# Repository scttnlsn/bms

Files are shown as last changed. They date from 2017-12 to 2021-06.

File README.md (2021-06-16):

# BMS

Integrated battery management system for 4-series li-ion packs (based on the [BQ76920](http://www.ti.com/product/BQ76920) from Texas Instruments).

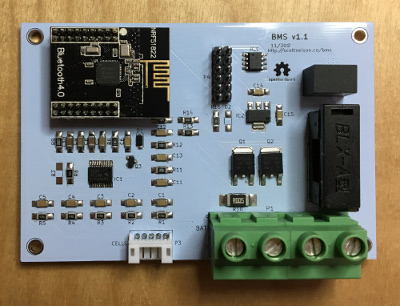
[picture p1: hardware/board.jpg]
Board


* programmable over/under voltage protection for each cell
* programmable short-circuit detection
* auto cell balancing
* cell voltage monitoring
* coulomb counting for accurate state-of-charge tracking
* status available over BLE

## Hardware

Full schematic and PCB layout available in the `hardware` directory.

* [TI BQ76920](http://www.ti.com/product/BQ76920) analog front-end
* [Nordic nRF51822](https://www.nordicsemi.com/eng/Products/Bluetooth-low-energy/nRF51822) ARM Cortex-M host controller
* FETs for enabling or disabling charge/discharge
* shunt resistor for current measurement

## Firmware

The host controller firmware is based on the [Zephyr RTOS](https://www.zephyrproject.org).  It communicates with the BQ76920 via I2C and handles various error states that may occur in the BQ76920.  It also exposes a BLE peripheral for wireless monitoring.

### Build

Requirements:

* [GNU ARM Embedded Toolchain](https://developer.arm.com/open-source/gnu-toolchain/gnu-rm)
* [OpenOCD](http://openocd.org)
* [Zephyr RTOS](https://www.zephyrproject.org) (included as submodule)
* [elftools](https://github.com/eliben/pyelftools)

Setup:

* `git submodule update --init`
* `./setup.sh`

Compile and flash:

* `make`
* `make flash`

### Configuration

There are various configuration options which can be specified via Kconfig.  Run `make menuconfig` to browse the available options and override any of the default values.

* `CONFIG_BMS_BOOT_DEVICE` (default: `GPIO_0`)
* `CONFIG_BMS_BOOT_PIN` (default: `21`)
* `CONFIG_BMS_ALERT_DEVICE` (default: `GPIO_0`)
* `CONFIG_BMS_ALERT_PIN` (default: `22`)
* `CONFIG_BMS_BLINK_DEVICE` (default: `GPIO_0`)
* `CONFIG_BMS_BLINK_PIN` (default: `18`)
* `CONFIG_BMS_OVP_ENABLE` (default: `3550` mV)
* `CONFIG_BMS_OVP_DISABLE` (default: `3350` mV)
* `CONFIG_BMS_UVP_ENABLE` (default: `3000` mV)
* `CONFIG_BMS_UVP_DISABLE` (default: `3100` mV)
* `CONFIG_BMS_SCD_DELAY` (default: `10000` ms)
* `CONFIG_BMS_OCD_DELAY` (default: `10000` ms)

## BLE Protocol

The BMS implements a Bluetooth Low Energy peripheral for monitoring cell voltages, current draw and state-of-charge.  All status data is part of a single characteristic.

Peripheral UUID: `8D9D7800-5B61-412A-AB71-5C7E0E559086`

Characteristic UUID: `8D9D7801-5B61-412A-AB71-5C7E0E559086`

Value structure (MSB to LSB):

* status [1 byte]
* cell 1 (mV) [2 bytes]
* cell 2 (mV) [2 bytes]
* cell 3 (mV) [2 bytes]
* cell 4 (mV) [2 bytes]
* current (mA) [2 bytes signed]
* charge used (mAs) [4 bytes signed]
* state of charge (percent) [1 byte]

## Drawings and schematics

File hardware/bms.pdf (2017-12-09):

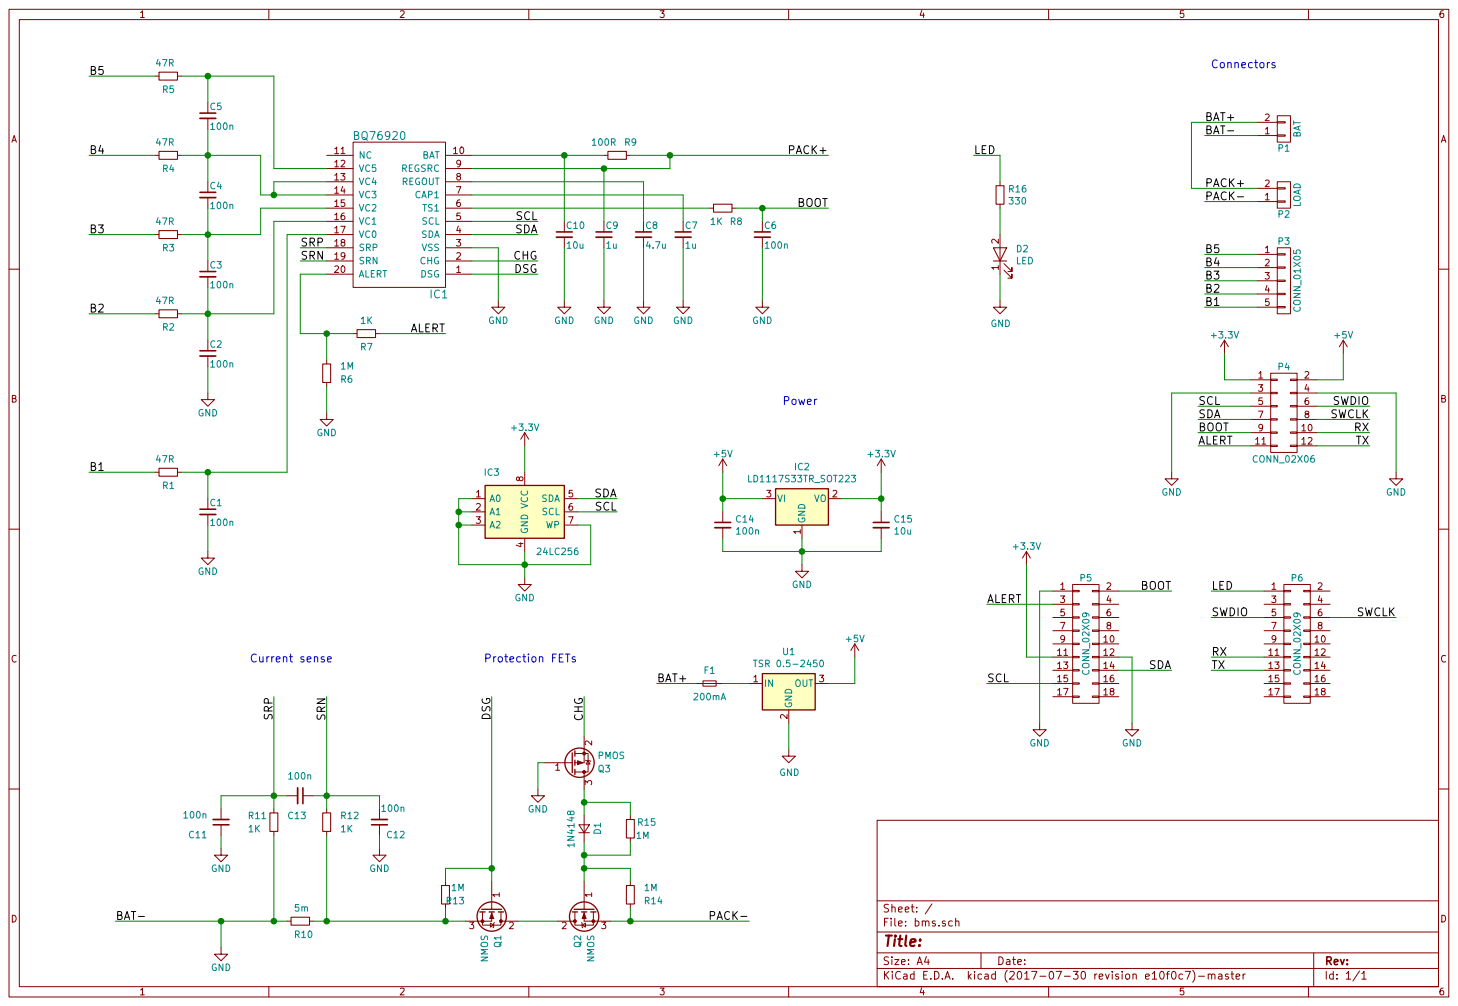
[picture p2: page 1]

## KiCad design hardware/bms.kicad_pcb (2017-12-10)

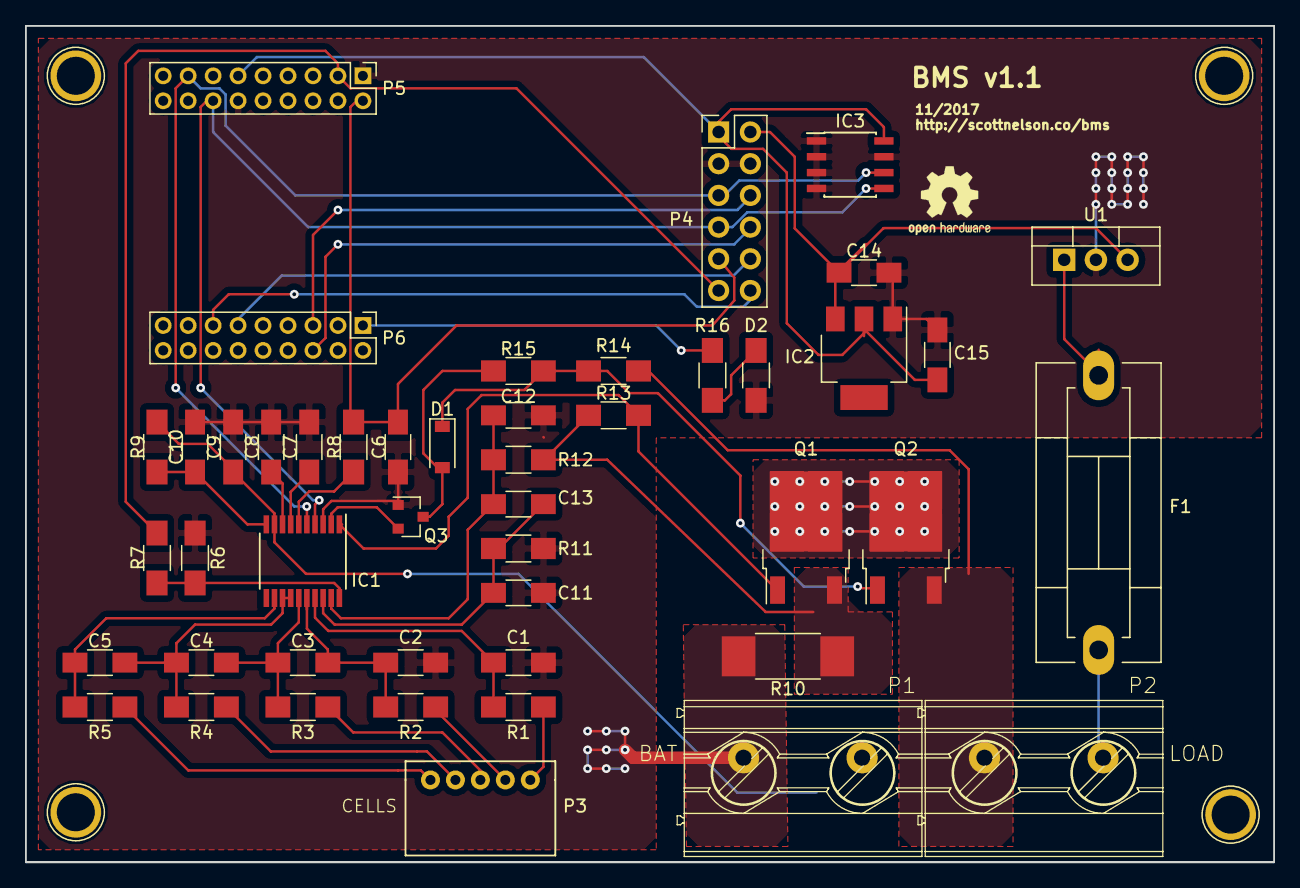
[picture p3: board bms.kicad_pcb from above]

Board: 2 copper layers, 100.0 x 67.0 mm, 47 parts (0 on the bottom side), 39 nets.

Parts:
C1, C2, C3, C4, C5, C6, C11, C12, C13, C14: 100n; C_1206_HandSoldering
C7, C9: 1u; C_1206_HandSoldering
C8: 4.7u; C_1206_HandSoldering
C10, C15: 10u; C_1206_HandSoldering
D1: 1N4148; D_SOD-123
D2: LED; R_1206_HandSoldering
F1: 200mA; Fuseholder5x20_horiz_SemiClosed_Casing10x25mm
IC1: BQ76920; TSSOP-20_4.4x6.5mm_Pitch0.65mm
IC2: LD1117S33TR_SOT223; SOT-223
IC3: 24LC256; SOIC-8_3.9x4.9mm_Pitch1.27mm
P1: BAT; MKDS_5-2-952
P2: LOAD; MKDS_5-2-952
P3: CONN_01X05; Molex_89401-0510
P4: CONN_02X06; Pin_Header_Straight_2x06_Pitch2.54mm
P5, P6: CONN_02X09; Pin_Header_Straight_2x09_Pitch2.00mm
Q1, Q2: NMOS; TO-252-2
Q3: PMOS; SOT-23
R1, R2, R3, R4, R5: 47R; R_1206_HandSoldering
R6, R13, R14, R15: 1M; R_1206_HandSoldering
R7, R8, R11, R12: 1K; R_1206_HandSoldering
R9: 100R; R_1206_HandSoldering
R10: 5m; R_2512_HandSoldering
R16: 330; R_1206_HandSoldering
U1: TSR 0.5-2450; TO-220-3_Vertical

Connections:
+3V3: C15.1, IC2.2, IC3.8, P4.1, P5.11
+5V: C14.1, IC2.3, P4.2, U1.3
/ALERT: P4.11, P5.3, R7.1
/B1: P3.5, R1.2
/B2: P3.4, R2.2
/B3: P3.3, R3.2
/B4: P3.2, R4.2
/B5: P3.1, R5.2
/BAT+: C9.1, F1.1, IC1.9, P1.2, P2.2, R9.1
/BOOT: C6.1, P4.9, P5.2, R8.1
/CHG: IC1.2, Q3.2
/DSG: IC1.1, Q1.1, R13.2
/LED: P6.1, R16.1
/PACK-: P2.1, Q2.3, R14.1
/RX: P4.10, P6.11
/SCL: IC1.5, IC3.6, P4.5, P5.15
/SDA: IC1.4, IC3.5, P4.7, P5.14
/SRN: C12.2, C13.1, IC1.19, R12.1
/SRP: C11.2, C13.2, IC1.18, R11.1
/SWCLK: P4.8, P6.6
/SWDIO: P4.6, P6.5
/TX: P4.12, P6.13
GND: C1.2, C2.2, C6.2, C7.2, C8.2, C9.2, C10.2, C11.1, C12.1, C14.2, C15.2, D2.1, IC1.3, IC2.1, IC3.1, IC3.2, IC3.3, IC3.4, IC3.7, P1.1, P4.3, P4.4, P5.1, P5.12, Q3.1, R6.1, R10.2, R11.2, U1.2
unnamed: C1.1, IC1.17, R1.1
unnamed: C2.1, C3.2, IC1.16, R2.1
unnamed: C3.1, C4.2, IC1.15, R3.1
unnamed: C4.1, C5.2, IC1.13, IC1.14, R4.1
unnamed: C5.1, IC1.12, R5.1
unnamed: C7.1, IC1.7
unnamed: C8.1, IC1.8
unnamed: C10.1, IC1.10, R9.2
unnamed: D1.1, Q2.1, R14.2, R15.2
unnamed: D1.2, Q3.3, R15.1
unnamed: D2.2, R16.2
unnamed: F1.2, U1.1
unnamed: IC1.6, R8.2
unnamed: IC1.20, R6.2, R7.2
unnamed: Q1.2, Q2.2
unnamed: Q1.3, R10.1, R12.2, R13.1

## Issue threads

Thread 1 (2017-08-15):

Atomic I2C reads

scttnlsn, 2017-08-15:
Currently starting separate I2C transactions to read 2 consecutive bytes which means the MSB and LSB of the voltage and current readings are not returned atomically.  Use a repeat start here to retrieve both bytes atomically.

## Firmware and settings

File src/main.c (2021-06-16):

#include <gpio.h>
#include <misc/printk.h>
#include <logging/sys_log.h>
#include <zephyr.h>

#include "ble.h"
#include "blinker.h"
#include "bms.h"

#define STACKSIZE 1024
#define PRIORITY 5

typedef struct __attribute__((__packed__)) {
  uint8_t status;
  uint16_t voltages[BMS_NUM_CELLS];
  int16_t current;
  int32_t charge;
  uint8_t soc;
} bms_data_t;

static bms_data_t bms_data;

// bms thread

K_THREAD_STACK_DEFINE(bms_thread_stack_area, STACKSIZE);
static struct k_thread bms_thread_data;

void bms_thread(void *a, void *b, void *c) {
  while (1) {
    bms_update();
    k_sleep(200);
  }
}

// serial logger thread

K_THREAD_STACK_DEFINE(logger_thread_stack_area, STACKSIZE);
static struct k_thread logger_thread_data;

void logger_thread(void *a, void *b, void *c) {
  while (1) {
    bms_data.status = bms_status();
    bms_cell_voltages(bms_data.voltages);
    bms_data.current = bms_current();
    bms_data.charge = bms_charge();
    bms_data.soc = bms_soc();

    printk("mV=%d, %d, %d, %d\n", bms_data.voltages[0], bms_data.voltages[1], bms_data.voltages[2], bms_data.voltages[3]);
    printk("mA=%d\n", bms_data.current);
    printk("charge=%d\n", bms_data.charge);
    printk("soc=%d\n", bms_data.soc);

    ble_notify((uint8_t *) &bms_data, sizeof(bms_data));

    k_sleep(2000);
  }
}

// serial logger thread

K_THREAD_STACK_DEFINE(flasher_thread_stack_area, STACKSIZE);
static struct k_thread flasher_thread_data;

void flasher_thread(void *a, void *b, void *c) {
  while (1) {
    blinker_flash();
    k_sleep(30000);
  }
}

void main(void) {
  SYS_LOG_INF("starting...");

  ble_init();
  blinker_init(CONFIG_BMS_BLINK_DEVICE, CONFIG_BMS_BLINK_PIN);

  int rc = bms_init();
  if (rc < 0) {
    SYS_LOG_INF("failed to initialize BMS");
    return;
  }

  k_thread_create(
    &bms_thread_data, bms_thread_stack_area,
    K_THREAD_STACK_SIZEOF(bms_thread_stack_area),
    bms_thread,
    NULL, NULL, NULL,
    PRIORITY, 0, K_NO_WAIT);

  k_thread_create(
    &logger_thread_data, logger_thread_stack_area,
    K_THREAD_STACK_SIZEOF(logger_thread_stack_area),
    logger_thread,
    NULL, NULL, NULL,
    PRIORITY, 0, K_NO_WAIT);

  k_thread_create(
    &flasher_thread_data, flasher_thread_stack_area,
    K_THREAD_STACK_SIZEOF(flasher_thread_stack_area),
    flasher_thread,
    NULL, NULL, NULL,
    PRIORITY, 0, K_NO_WAIT);

  SYS_LOG_INF("started");
}

void _SysFatalErrorHandler(unsigned int reason, const NANO_ESF *pEsf) {
  blinker_on();
  while (1);
}

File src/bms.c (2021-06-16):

#include <gpio.h>
#include <logging/sys_log.h>
#include <string.h>
#include <zephyr.h>

#include "bms.h"
#include "bq769x0.h"

static uint8_t status;
static uint8_t cells[BMS_NUM_CELLS] = { 0, 1, 2, 4, };
static uint16_t cell_voltages[BMS_NUM_CELLS];
static int16_t current; // most recent 250ms current average
static u64_t capacity = BMS_NOMINAL_CAPACITY;
static s64_t charge = -1; // cumulative mA seconds
static uint8_t ov = 0;
static uint8_t uv = 0;
static uint8_t scd = 0;
static s64_t scd_tick = 0;
static uint8_t ocd = 0;
static s64_t ocd_tick = 0;

void bms_handle_error(uint8_t status);
void bms_interpolate_charge(void);

static struct gpio_callback alert_cb;

static void bms_alert(struct device *gpiob, struct gpio_callback *cb, u32_t pins) {
  // TODO
}

int bms_init(void) {
  int rc;

  SYS_LOG_INF("initializing...");

  // setup alert interrupt
  struct device *gpio = device_get_binding(CONFIG_BMS_ALERT_DEVICE);
  if (gpio == NULL) {
    SYS_LOG_ERR("failed to get binding for %s", CONFIG_BMS_ALERT_DEVICE);
    return -EINVAL;
  }

  gpio_pin_configure(gpio, CONFIG_BMS_ALERT_PIN, GPIO_DIR_IN | GPIO_INT | GPIO_INT_EDGE | GPIO_INT_ACTIVE_HIGH | GPIO_PUD_PULL_DOWN);
  gpio_init_callback(&alert_cb, bms_alert, BIT(CONFIG_BMS_ALERT_PIN));
  gpio_add_callback(gpio, &alert_cb);
  gpio_pin_enable_callback(gpio, CONFIG_BMS_ALERT_PIN);

  rc = bq769x0_init(CONFIG_BMS_I2C_DEVICE);
  if (rc < 0) {
    SYS_LOG_ERR("failed to initialize BQ769x0");
    return rc;
  }

  rc = bq769x0_boot(CONFIG_BMS_BOOT_DEVICE, CONFIG_BMS_BOOT_PIN);
  if (rc < 0) {
    SYS_LOG_ERR("failed to boot BQ769x0");
    return rc;
  }

  bq769x0_config_t bq769x0_config;
  bq769x0_config.ovp = CONFIG_BMS_OVP_ENABLE;
  bq769x0_config.uvp = CONFIG_BMS_UVP_ENABLE;

  rc = bq769x0_configure(bq769x0_config);
  if (rc < 0) {
    SYS_LOG_ERR("failed to configure BQ769x0");
    return rc;
  }

  rc = bq769x0_balance_cell(-1);
  if (rc < 0) {
    return rc;
  }

  rc = bq769x0_enable_charging();
  if (rc < 0) {
    return rc;
  }

  rc = bq769x0_enable_discharging();
  if (rc < 0) {
    return rc;
  }

  SYS_LOG_INF("initialized");
  return 0;
}

// should be called at least every 250ms for accurate coulomb counting
int bms_update(void) {
  int rc;

  rc = bq769x0_read_status(&status);
  if (rc < 0) {
    return rc;
  }

  uint8_t error = bq769x0_status_error(status);
  if (error) {
    bms_handle_error(error);
  }

  for (int i = 0; i < BMS_NUM_CELLS; i++) {
    bq769x0_read_voltage(cells[i], &cell_voltages[i]);
  }

  if (charge == -1) {
    bms_interpolate_charge();
  }

  uint8_t cc_ready = bq769x0_cc_ready(status);
  if (cc_ready) {
    bq769x0_read_current(&current);
    charge += (current / 4); // CC updated every 250ms
  }

  if (scd) {
    if (k_uptime_get() - scd_tick > CONFIG_BMS_SCD_DELAY) {
      bq769x0_clear_status(BQ769X0_STATUS_SCD);
      bq769x0_enable_charging();
      bq769x0_enable_discharging();
    } else {
      return 0;
    }
  }

  if (ocd) {
    if (k_uptime_get() - ocd_tick > CONFIG_BMS_OCD_DELAY) {
      bq769x0_clear_status(BQ769X0_STATUS_OCD);
      bq769x0_enable_charging();
      bq769x0_enable_discharging();
    } else {
      return 0;
    }
  }

  if (ov) {
    // check to see if voltages have fallen enough to disable OVP
    uint8_t disable = 1;

    for (int i = 0; i < BMS_NUM_CELLS; i++) {
      disable = disable & (cell_voltages[i] <= CONFIG_BMS_OVP_DISABLE);
    }

    if (disable) {
      bq769x0_clear_status(BQ769X0_STATUS_OV);
      bq769x0_enable_charging();
    }
  }

  if (uv) {
    // check to see if voltages have risen enough to disable UVP
    uint8_t disable = 1;

    for (int i = 0; i < BMS_NUM_CELLS; i++) {
      disable = disable & (cell_voltages[i] >= CONFIG_BMS_UVP_DISABLE);
    }

    if (disable) {
      bq769x0_clear_status(BQ769X0_STATUS_UV);
      bq769x0_enable_discharging();
    }
  }

  return 0;
}

uint8_t bms_status() {
  return status & 0xF; // only include: UV | OV | SCD | OCD |
}

int bms_cell_voltages(uint16_t *voltages) {
  int len = sizeof(cell_voltages);
  memcpy(voltages, cell_voltages, len);
  return len;
}

int16_t bms_current(void) {
  return current;
}

int32_t bms_charge(void) {
  return charge;
}

uint8_t bms_soc(void) {
  return (capacity + charge) * 100 / capacity;
}

// helpers

void bms_handle_error(uint8_t status) {
  SYS_LOG_INF("error status: %d", status);

  if (status & 0b00000100) {
    // over voltage
    if (!ov) {
      SYS_LOG_ERR("over voltage limit");
      ov = 1;
      charge = 0;
    }
  } else {
    ov = 0;
  }

  if (status & 0b00001000) {
    // under voltage
    if (!uv) {
      SYS_LOG_ERR("under voltage limit");
      uv = 1;
      capacity = -charge;

      // TODO: persist updated capacity
    }

    // TODO: probably shut down the MCU here as well since it continues to draw current
  } else {
    uv = 0;
  }

  if (status & 0b00000010) {
    // short circuit
    if (!scd) {
      SYS_LOG_ERR("short circuit");
      scd_tick = k_uptime_get();
    }
    scd = 1;
  } else {
    scd = 0;
  }

  if (status & 0b00000001) {
    // overcurrent discharge
    if (!ocd) {
      SYS_LOG_ERR("overcurrent discharge");
      ocd_tick = k_uptime_get();
    }
    ocd = 1;
  } else {
    ocd = 0;
  }
}

void bms_interpolate_charge(void) {
  SYS_LOG_INF("interpolating charge");

  uint32_t average_cell_voltage = 0;
  for (int i = 0; i < BMS_NUM_CELLS; i++) {
    average_cell_voltage += cell_voltages[i];
  }

  average_cell_voltage /= BMS_NUM_CELLS;

  uint32_t mv_range = CONFIG_BMS_OVP_ENABLE - CONFIG_BMS_UVP_ENABLE;
  u64_t capacity_per_mv = BMS_NOMINAL_CAPACITY / mv_range;
  uint32_t mv_offset = CONFIG_BMS_OVP_ENABLE - average_cell_voltage;

  charge = -(capacity_per_mv * mv_offset);
}

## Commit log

2017-07-21 Added cell voltage logging
2017-07-28 Added alert interrupt handling
2017-07-29 Added basic BLE peripheral for monitoring cell voltages and pack current
2017-07-31 Enable pull down on alert pin
    There's a pull down on the board but was seeing OVRD_ALERT when sending alert signal over ~10" wire
2017-07-31 Perform continuous current monitoring
2017-07-31 Extract device names and pin numbers into Kconfig options
2017-07-31 Disable OVP/UVP when voltages have recovered sufficiently
2017-08-01 Recover from SCD and OCD errors after delay
    [bms.c, bq769x0.c]
2017-08-02 Send charge with BLE notification data
2017-08-02 Calculate SOC based on cumulative charge and battery capacity
2017-08-02 Improved capacity/charge handling
2017-08-28 Steady LED when there's a fault
2017-09-20 Added CRC bytes to all I2C messages
2017-12-09 Added hardware
    [bms.kicad_pcb, bms.sch]
2017-12-10 Fix regulator grounding issue on PCB
    [bms.kicad_pcb]
